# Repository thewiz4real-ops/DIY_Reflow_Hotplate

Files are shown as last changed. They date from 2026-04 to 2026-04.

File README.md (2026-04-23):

# DIY Reflow Hotplate

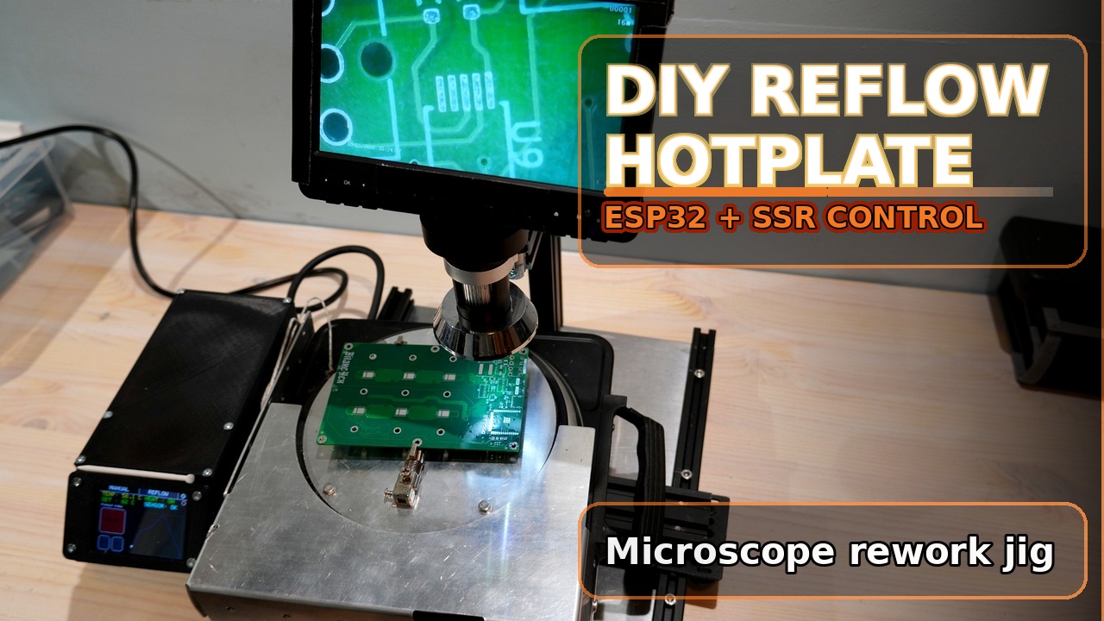
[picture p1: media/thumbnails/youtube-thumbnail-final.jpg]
DIY reflow hotplate thumbnail


DIY PCB reflow hotplate and microscope rework jig built around a 1500 W single-burner hotplate, a large aluminum work surface, and an ESP32 touchscreen controller.

The original goal was to make large-board repair and preheating easier under a microscope, then extend the same machine into a basic reflow station.

YouTube build video: [https://youtu.be/tEUVSpoKs-g](https://youtu.be/tEUVSpoKs-g)

> This is a hobby / experimental project, not a certified product. If you build, copy, modify, or use anything from this repo, you do so at your own risk and under your own responsibility.

## What is in this repo

- cleaned-up project documentation
- ESP-IDF 5.5 firmware in `firmware/esp-idf-5.5/`
- Arduino sketch version in `firmware/arduino/hotplate_controller/`
- BOM with part links and raw build notes in `bom/`
- CAD files for the main plate and the control box enclosure
- build photos and the final YouTube thumbnail

## Current status

This machine works as a PCB preheater and rework station, and it can also run a reflow profile. It is still an experimental build, and the main thing still left to tune is the final calibration between the displayed temperature and the real working surface.

If you want the full build sequence, the YouTube video is the best companion to this repo. The repo keeps the important design choices, troubleshooting notes, and source files, while the video shows the complete build process.

## Main features

- 1500 W hotplate base with aluminum top plate
- rotating work surface for microscope work
- hand rest / armature around the hot zone
- ESP32 touchscreen controller with graph UI
- SSR-controlled heater output
- 100k NTC temperature sensing
- manual mode, reflow mode, and saved settings
- controller mounted close to the moving work area

## Build summary

- The project started because the Betax Hex PCB had large copper planes that were difficult to reflow with hot air alone.
- The first version was a simple hotplate with a marked mechanical thermostat and a laser-thermometer-verified preheat point.
- The final direction became a safer microscope rework jig with a rotating plate, hand rest, motion system, and ESP32 touchscreen control.
- The most important fixes were the display driver setup, the wrong 3.3 V header-pin mistake, and removing the thermal gap between the hotplate and the work plate.

## Safety

This project uses mains voltage, high current, and hot metal surfaces.

It is shared as build documentation for a personal hobby project. I cannot take responsibility for injury, fire, property damage, or other loss caused by building or using this project.

- build it only if you understand the electrical and thermal risks
- bond all intended metal chassis parts to earth
- use proper insulation, strain relief, and enclosure design
- never leave the machine unattended while powered or hot
- if you replicate the controller power supply, use a properly enclosed certified 5 V PSU instead of modifying a loose phone charger

## Repo layout

- `bom/` parts list, purchase links, and raw source notes
- `docs/` overview, build notes, firmware notes, tuning notes, and safety notes
- `firmware/` Arduino and ESP-IDF firmware versions
- `hardware/` controller, enclosure, and wiring documentation
- `mechanical/` frame, armature, and CAD files
- `media/` build photos, thumbnail, and video link
- `notes/` GitHub publishing helpers

## Quick start

1. Read `docs/07_safety.md` first.
2. Start with `docs/01_project_overview.md` and `docs/02_mechanical_build.md`.
3. Use `bom/BOM.md` or `bom/BOM.csv` for parts.
4. Choose either the Arduino or ESP-IDF firmware path under `firmware/`.
5. Calibrate the machine before trusting the displayed temperature.

## Still to finish

- final calibration table that maps setpoint to real surface temperature

## Possible separate project

- A small controller PCB for the MOSFET and resistor section would be a natural spinoff from the current perfboard version.

## License

This repository is released under the MIT License. See `LICENSE`.

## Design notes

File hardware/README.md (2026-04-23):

# Hardware

This folder stores the controller hardware, enclosure files, and wiring notes.

## Main sections

- `controller-board/` for breadboard, perfboard, and controller-board notes
- `enclosure/` for the control box enclosure files
- `wiring/` for the pin map and wiring references

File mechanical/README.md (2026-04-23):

# Mechanical files

This folder stores the frame, armature, microscope mount, and CAD/CAM notes.

## Main sections

- `frame/` for the base structure and main plate CAD files
- `armature/` for the hand-rest / heat shield notes
- `microscope-mount/` for the microscope support

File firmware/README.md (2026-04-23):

# Firmware

Two firmware versions are included in this repo:

- `arduino/hotplate_controller/` for the Arduino IDE style sketch
- `esp-idf-5.5/` for the ESP-IDF 5.5 project using Arduino as a component

Both versions target the same ESP32 touchscreen controller and share the same basic feature set:

- Manual mode
- Reflow mode
- Settings page
- XPT2046 touch input
- NTC temperature reading
- SSR heater control
- settings saved in flash

## Shared pin summary

- NTC sensor: GPIO 35
- SSR output: GPIO 27
- touch IRQ: GPIO 36
- touch MOSI: GPIO 32
- touch MISO: GPIO 39
- touch CLK: GPIO 25
- touch CS: GPIO 33

## Important note

The display still depends on a correct `TFT_eSPI` configuration for the exact CYD board and panel driver.

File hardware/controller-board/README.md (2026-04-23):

# Controller board

The original build used:
1. a breadboard prototype
2. a perfboard implementation

This folder documents the controller-side hardware for the build.

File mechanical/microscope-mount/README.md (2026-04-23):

# Microscope mount

This folder covers the center-mounted microscope support used in the build.

The mount concept and layout are described in `docs/02_mechanical_build.md` and shown in the YouTube video.

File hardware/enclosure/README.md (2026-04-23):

# Electronics enclosure

3D printed enclosure for:
- SSR
- 5 V supply
- main power switch
- touchscreen window

Also note:
- zip-tie anchor holes
- cable routing channels
- relay bolt-through mount to aluminum chassis

## Files currently in the repo

The current source exports are under `cad/brain-box/`:

- `reflow-plate-brain-box.f3d`
- `reflow-plate-brain-box.3mf`
- `reflow-plate-brain-box.obj`
- `reflow-plate-brain-box.mtl`

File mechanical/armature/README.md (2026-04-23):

# Armature / hand-rest

Purpose:
- give a cooler place to rest the hand
- improve comfort during microscope work
- reduce accidental contact with the hot area

Build notes:
- made from 2 mm aluminum
- designed as a foldable sheet part
- grooves added to help controlled bending
- mounted with aluminum rivets
- spaced away from the hot zone with bolts / spacers

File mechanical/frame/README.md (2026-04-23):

# Frame

Main structure made from:
- 50 x 50 cm aluminum base plate
- T-slot profiles
- drilled and tapped mounting holes

Suggested things to document:
- exact profile lengths
- exact hole spacing
- wheel setup
- microscope mount dimensions
- control box bracket dimensions

## Files currently in the repo

The main plate CAD exports are in `cad/reflow-plate/`:

- `reflow-plate.f3d`
- `reflow-plate.3mf`
- `reflow-plate.obj`
- `reflow-plate.mtl`

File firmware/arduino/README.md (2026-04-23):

# Arduino Firmware

The Arduino version of the controller lives in `hotplate_controller/hotplate_controller.ino`.

## Expected libraries

- `TFT_eSPI`
- `XPT2046_Touchscreen`
- `Preferences`

## Notes

- this sketch targets the ESP32-2432S028 style CYD board
- touch and heater pins match the ESP-IDF version
- `TFT_eSPI` requires the correct board-specific `User_Setup.h`

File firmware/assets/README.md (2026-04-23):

# Firmware assets

The current interface is drawn directly in code.

This folder is available for any optional logos, icons, splash images, or calibration graphics associated with the firmware.

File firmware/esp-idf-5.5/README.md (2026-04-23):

# ESP-IDF 5.5 hotplate project

This project keeps the UI and control logic in Arduino-style C++, but runs inside an ESP-IDF project using Arduino as a component.

## What is included
- `main/main.cpp` contains the hotplate app
- raw XPT2046 touch handling is built into `main.cpp`
- `TEMP_OFFSET_C` is stored in Preferences / NVS
- settings selection uses one large `NEXT` button
- touch reading uses median filtering for better tap stability

## Dependency setup
Clone `TFT_eSPI` into `components/TFT_eSPI`.

Example:
```bash
cd components
git clone https://github.com/Bodmer/TFT_eSPI.git
```

Then copy the working `User_Setup.h` / `User_Setup_Select.h` into that library, because the display wiring and driver config live there.

## Build steps
```bash
idf.py set-target esp32
idf.py build
idf.py -p PORT flash monitor
```

## Notes
- Arduino is pulled in by `main/idf_component.yml`
- the `components/` folder is included so the `TFT_eSPI` checkout has a clear home
- touch uses these pins:
  - IRQ 36
  - MOSI 32
  - MISO 39
  - CLK 25
  - CS 33
- if touch still lands off near the edges, recalibrate:
  - `XMIN`
  - `XMAX`
  - `YMIN`
  - `YMAX`

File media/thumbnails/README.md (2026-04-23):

# Thumbnails

Current file:

- `youtube-thumbnail-final.jpg`

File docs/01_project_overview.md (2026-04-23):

# Project overview

## Why this was built

This project started after building the Betax Hex, a large PCB with heavy copper layers. Hot-air-only reflow was hard because the board absorbed heat too fast. Solder cooled quickly, alignment was poor, and rework was uncomfortable.

The target was a setup that is:
- stable
- safe to handle
- controllable
- repeatable
- usable under a microscope
- suitable for both repair work and reflow

## Final goal

One machine that can be used as:
- a heat plate for repair and preheating
- a reflow plate when needed
- a safer microscope work area with a hand-rest

## Build path

The project did not start as the final rail-based machine.

The first version was a 1500 W cooking hotplate with a 2 mm aluminum top plate and a PCB holder. Because the hotplate only had a mechanical thermostat, a laser thermometer was used to find and mark a repeatable preheat position around 100 C.

That first version proved the thermal idea, but it was awkward and unsafe to use under a microscope. Burned fingers and poor ergonomics pushed the project toward a full mechanical redesign with a hand rest, motion system, rotating work area, and ESP32 control box.

## Full build log

The repo keeps the key files and lessons learned. For the full sequence of fabrication and assembly steps, use the YouTube video linked from the main `README.md`.

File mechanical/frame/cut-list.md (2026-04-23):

# Frame cut list

This cut list includes the dimensions that were clearly recorded during the build.

| Part | Material | Qty | Length / Size | Notes |
|---|---|---:|---|---|
| Base plate | Aluminum | 1 | 500 x 500 x 10 mm | Main base |
| Top working plate | Aluminum | 1 | 8 mm or 10 mm | Builder used 10 mm plate |
| Secondary plate | Aluminum | 1 | Match top plate footprint | Final no-gap thermal fix |
| 2040 profile | T-slot | 1 | 500 mm | Explicitly mentioned in raw notes |
| Additional frame profiles | T-slot | Varies | Varies by build | Depends on the final rail and microscope layout |
| Gantry plate | Off-the-shelf wheel carriage | Varies | 80 mm format | Motion assembly part |
| Control box bracket | Aluminum | 1 | Custom fit | Dimensions follow the finished control-box position |

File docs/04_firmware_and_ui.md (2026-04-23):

# Firmware and UI

## Repo layout
- Arduino sketch: `firmware/arduino/hotplate_controller/hotplate_controller.ino`
- ESP-IDF project: `firmware/esp-idf-5.5/`

## Hardware stack
- ESP32 touchscreen board
- TFT_eSPI for display
- XPT2046 for touch
- Preferences / NVS for saved settings

## Why not LVGL
LVGL caused configuration and version mismatch problems during development, so the firmware moved to a simpler TFT_eSPI + XPT2046 setup.

The main problems were missing `lv_conf.h` setup and LVGL v8/v9 mismatch issues during compile-time testing.

## Display bring-up problems

Early display tests had split-screen output, noise, and black-screen behavior.

The working fix was:
- use the `ILI9341_2` driver configuration
- enable `TFT_INVERSION_ON`

That combination gave a stable display on the CYD hardware used in this build.

## UI structure
- Manual tab
- Reflow tab
- Settings tab

## Manual mode
- user selects temperature
- ramped setpoint behavior helps reduce overshoot
- can be used like a repair / preheat mode

## Reflow mode
- full profile
- stage display
- graph / progress indicator
- pause behavior if the plate falls behind the profile

## Settings
- approach band
- burst window
- max power limit
- values saved in flash

## Shared control I/O
- NTC ADC input on GPIO 35
- heater output on GPIO 27
- XPT2046 touch on GPIO 36, 32, 39, 25, and 33

## UI optimization
- small-region redraw instead of full-screen redraw
- touch debouncing / better click handling
- improved touch stability from debounce and target locking behavior
- improved stability and reduced flicker

## Important setup note
`TFT_eSPI` relies on a working `User_Setup.h` / `User_Setup_Select.h` for the specific CYD display wiring and driver configuration.

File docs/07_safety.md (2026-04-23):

# Safety

This repo documents a hobby / experimental project. It is not a certified appliance, a commercial product, or a guarantee that the design is safe for replication.

If you build, copy, modify, or use anything from this project, you do so at your own risk and under your own responsibility. The builder of this repo cannot take responsibility for injury, fire, property damage, or other loss.

This project uses:
- mains voltage
- high current
- hot surfaces
- exposed metal structure near electrical parts

## Minimum safety expectations
- earth / ground all intended metal chassis parts
- check continuity from mains earth to grounded metal parts
- secure cables so they cannot move
- keep mains and low-voltage wiring organized
- use proper strain relief
- insulate exposed joints
- mount the SSR correctly
- verify the enclosure is safe before power-on
- do not leave the machine unattended

## Public repo recommendation
Treat the repo as documentation of an experimental build, not a certification claim.

Suggested wording:
> Build and use at your own risk. This is a hobby project, not a certified commercial appliance.

## Safer design ideas
If you ever make a more replication-focused version, add:
- proper cable gland
- independent thermal cutoff / fuse
- dedicated earth lug to chassis
- safer low-voltage PSU choice
- standard sensor mounting method

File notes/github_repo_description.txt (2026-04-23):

DIY PCB reflow hotplate and microscope rework jig with ESP32 touchscreen control, SSR heater switching, custom aluminum mechanics, and Arduino + ESP-IDF firmware.

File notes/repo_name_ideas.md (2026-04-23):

# Repo name ideas

- diy-reflow-hotplate
- esp32-reflow-hotplate
- microscope-rework-hotplate
- pcb-preheater-rework-jig
- diy-hotplate-rework-station

Simple recommendation:
`diy-reflow-hotplate`

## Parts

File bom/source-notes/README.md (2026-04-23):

# Source Notes

`mybom_raw_links.txt` is the original rough purchase list from the build. It is kept here as a raw reference so the cleaned BOM files can stay readable without losing the original notes.

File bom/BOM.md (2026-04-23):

# Bill of Materials

This is the main human-readable BOM for the project. It merges the cleaned part list with the original rough purchase links so the important URLs, part numbers, and notes are all in one place.

Use `BOM.csv` if you want to sort or filter the same list in a spreadsheet.

## Main BOM

| Category | Item | Qty | Link / Source | Part number | Notes |
|---|---|---:|---|---|---|
| Hotplate | Day single burner hotplate, 18 cm, 1500 W | 1 | https://www.megaflis.no/kjokken/kjokkenapparater/diverse-kjokkenapparater/day-kokeplate-o18cm-1500w? |  | Main heater base |
| Mechanical | Aluminum top plate | 1 | https://www.aliexpress.com/item/1005009533760651.html |  | Builder note says 8 mm or 10 mm works; this build used 10 mm |
| Mechanical | Aluminum base plate | 1 | Local / custom stock |  | 500 x 500 x 10 mm main base plate |
| Mechanical | Secondary aluminum plate | 1 | Reused part |  | Added during the final no-gap thermal fix |
| Mechanical | Armature sheet | 1 | Local / custom stock |  | 2 mm aluminum sheet for the hand rest / armature |
| Motion | 80 mm gantry plate | 1 | https://www.temu.com/goods.html?_bg_fs=1&goods_id=601099519049945 |  | V-slot gantry plate used in the motion assembly |
| Motion | V-slot wheel kit | 2 | https://www.temu.com/no-en/3d-printer-additions-for--v-shaped--plate-set-special-skate-wheels-compatible-with-2020-2040-v-slot-profiles-g-606143246110085.html |  | Openbuild-style wheel set for 2020 / 2040 profiles |
| Motion | T-slot extrusion | Varies | https://www.temu.com/no-en/t-slot-2020-extrusion-european-standard-anodized-linear-rail-for-3d-printer-parts-and-cnc-diy-black-g-606341536023071.html |  | Black anodized extrusion for frame and microscope support; lengths depend on the final cut list |
| Motion | 2040 extrusion, 500 mm | 1 | https://www.aliexpress.com/item/1005004784760394.htm |  | Explicitly mentioned in the raw notes |
| Motion | Extrusion bracket set | 1 kit | https://www.temu.com/goods.html?_bg_fs=1&goods_id=601099554813640 |  | Joint plates, T-nuts, and M5 x 8 mm screws for the frame |
| Electronics | ESP32-2432S028 CYD display board | 1 | https://www.aliexpress.com/item/1005008314695130.html |  | Main controller |
| Electronics | Crydom D2425 SSR | 1 | Digikey | D2425 / CC1006-ND | SSR relay, SPST-NO, 25 A, 24-280 V |
| Electronics | NTC thermistor | 1 | Digikey | NRBG105F3950B1F / 283-NRBG105F3950B1F-ND | 100k NTC, beta 3950, 1 percent |
| Electronics | IRLZ44NPBF MOSFET | 1 | Generic supplier / existing stock | IRLZ44NPBF | Used in the driver section |
| Electronics | Perfboard | 1 | Generic supplier / existing stock |  | Used for the final controller wiring |
| Electronics | JST-style connectors | 2 | Generic supplier / existing stock |  | JST-style plug connectors were used on the perfboard build; quantity is a builder estimate |
| Electronics | Resistor assortment | 1 pack | Generic supplier / AliExpress |  | Raw note says generic resistor package from AliExpress |
| Power | 5 V phone charger | 1 | Reused part |  | Original build reused this for ESP32 power; safer enclosed PSU is recommended for copies |
| Power | Power switch from extension strip | 1 | https://www.biltema.no/bygg/elektro/grenkontakter/grenkontakt-jordet/grenuttak-med-bryter-5-veis-hvitt-15-m-2000048332 |  | Original build reused only the switch |
| Optics | Digital microscope | 1 | https://www.temu.com/goods.html?_bg_fs=1&goods_id=601099593977408 |  | DM9-style microscope with LED lighting |
| Fasteners | M4 hex-head screws | Varies | Local hardware store / existing stock |  | Used throughout the tapped aluminum parts; length depends on mounting location |
| Fasteners | Wood screws, 3 x 15 mm | 1 pack | https://www.biltema.no/bygg/festeelementer/treskruer/treskrue-3-x-15-200-stk-2000058078 |  | Utility screw pack used during the build |
| Wiring | Hookup wire | As needed | Generic supplier / existing stock |  | Thin stranded wire used like manual traces on perfboard |
| Wiring | Mains cable | 1 | Generic supplier / existing stock |  | Use proper strain relief and enclosure routing |
| Consumables | UV resin | 1 | Generic supplier / existing stock |  | Used to secure and insulate some mains-side joints |
| Consumables | Ceramic cement | 1 | Generic supplier / existing stock |  | Used during one thermistor mounting experiment |
| Consumables | Fiberglass gasket | 1 | Generic supplier / existing stock |  | 6 mm; used in one thermal gap experiment |
| Tools | M4 tap | 1 | Local hardware store / existing stock |  | Used for tapping threaded holes in the aluminum parts |
| Tools | Profile drilling guide | 1 | https://www.temu.com/no-en/drilling-guide-for-vertical--designed-for-20-30-and-40-aluminum-profiles-featuring-sliders-and-an-m6-countersunk-step-drill-g-601103103107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 |  | Optional helper for aluminum profiles |
| Tools | Laser thermometer | 1 | Existing tool |  | Used to find a repeatable early preheat point |
| Tools | Hot air gun | 1 | Existing tool |  | Used during rework and bench testing |

## Notes

- Quantities marked `Varies` or `As needed` depend on the exact build layout rather than a single fixed number.
- The original rough purchase note file is still kept in `source-notes/mybom_raw_links.txt` as an archive, but the important link data is merged into this file.
- For public safety, it is better to recommend a properly enclosed certified 5 V PSU instead of copying the reused phone-charger approach from the original build.

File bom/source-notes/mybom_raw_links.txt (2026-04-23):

https://www.aliexpress.com/item/1005009533760651.html Aluminum Metal Shee 8mm or 10mm wil work, mine was 10mm

https://www.aliexpress.com/item/1005008314695130.html ESP32 MCU 2.8 Inch Smart Display for Arduino

https://www.temu.com/goods.html?_bg_fs=1&goods_id=601099593977408 Microscope with Leds 1200X Magnification DM9 1080P HD Soldring Microscope for Electronics Repair

https://www.temu.com/goods.html?_bg_fs=1&goods_id=601099519049945 80Mm Gantry Plate with Wheels for Profiles V-Slot Plate Kits Plat V-Openbuildd

https://www.temu.com/no-en/3d-printer-additions-for--v-shaped--plate-set-special-skate-wheels-compatible-with-2020-2040-v-slot-profiles-g-606143246110085.html 
Openbuild, V-Shaped Gantry Plate Set, Special Skate Wheels, Compatible with 2020/2040 V-Slot Profiles

https://www.temu.com/no-en/t-slot-2020-extrusion-european-standard-anodized-linear-rail-for-3d-printer-parts-and-cnc-diy-black-g-606341536023071.html
Standard Anodized Linear Rail for 3D Printer Parts and CNC DIY Black

https://www.temu.com/no-en/drilling-guide-for-vertical--designed-for-20-30-and-40-aluminum-profiles-featuring-sliders-and-an-m6-countersunk-step-drill-g-601103103107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
Punchers Designed for 20#, 30#, And 40# Aluminum Profiles, Featuring Sliders And an M6 Countersunk Step Drill

https://www.aliexpress.com/item/1005004784760394.htm
1PCS 2040 500mm

https://www.biltema.no/bygg/festeelementer/treskruer/treskrue-3-x-15-200-stk-2000058078
Treskrue 3 x 15, 200 stk.

https://www.temu.com/goods.html?_bg_fs=1&goods_id=601099554813640
Extrusion Bracket Set - Including 8pcs Joint Plates, 1pc M3 Wrench, 40pcs M5 T-Slot Nuts, 40pcs M5x8mm Screws, For 3D Printer Frame

digikey

283-NRBG105F3950B1F-ND
NRBG105F3950B1F
NTC 100K 3950K BETA 25/50 1%

CC1006-ND
D2425
SSR RELAY SPST-NO 25A 24-280V

mosfet
IRLZ44NPBF

generic resistor package from AliExpress

power buton from this removit from this extenstion cable
https://www.biltema.no/bygg/elektro/grenkontakter/grenkontakt-jordet/grenuttak-med-bryter-5-veis-hvitt-15-m-2000048332

Day kokeplate ø18cm 1500w
https://www.megaflis.no/kjokken/kjokkenapparater/diverse-kjokkenapparater/day-kokeplate-o18cm-1500w?

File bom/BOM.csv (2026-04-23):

Category | Item | Description | Qty | Status | Link | Notes
Hotplate | Day single burner hotplate | 18 cm, 1500 W hotplate used as the heater base | 1 | Used in build | https://www.megaflis.no/kjokken/kjokkenapparater/diverse-kjokkenapparater/day-kokeplate-o18cm-1500w? | Main heater base
Mechanical | Top aluminum plate | Aluminum sheet for the heated work surface | 1 | Used in build | https://www.aliexpress.com/item/1005009533760651.html | Builder note says 8 mm or 10 mm works and this build used 10 mm
Mechanical | Base plate | Main aluminum base plate | 1 | Used in build |  | 500 x 500 x 10 mm
Mechanical | Secondary aluminum plate | Second plate used during the final no-gap thermal fix | 1 | Used in build |  | Stacked directly with the top plate
Mechanical | Armature sheet | 2 mm aluminum sheet for the hand rest / armature | 1 | Used in build |  | Folded sheet-metal style part
Motion | 80 mm gantry plate | V-slot gantry plate used in the motion assembly | 1 | Used in build | https://www.temu.com/goods.html?_bg_fs=1&goods_id=601099519049945 | Single gantry plate used in the motion assembly
Motion | V-slot wheel kit | Wheel set for 2020 / 2040 profiles | 2 | Used in build | https://www.temu.com/no-en/3d-printer-additions-for--v-shaped--plate-set-special-skate-wheels-compatible-with-2020-2040-v-slot-profiles-g-606143246110085.html | Two kits used in the build
Motion | T-slot extrusion | Black anodized extrusion for frame and microscope support | Varies | Used in build | https://www.temu.com/no-en/t-slot-2020-extrusion-european-standard-anodized-linear-rail-for-3d-printer-parts-and-cnc-diy-black-g-606341536023071.html | Lengths depend on the final cut list
Motion | 2040 extrusion 500 mm | One explicitly noted 2040 profile length from the build notes | 1 | Used in build | https://www.aliexpress.com/item/1005004784760394.htm | Raw note says 1 pcs 2040 500 mm
Motion | Extrusion bracket set | Joint plates, T-nuts, and M5 screws for the frame | 1 kit | Used in build | https://www.temu.com/goods.html?_bg_fs=1&goods_id=601099554813640 | Frame hardware kit
Tools | Profile drilling guide | Drilling guide for aluminum profiles | 1 | Tool | https://www.temu.com/no-en/drilling-guide-for-vertical--designed-for-20-30-and-40-aluminum-profiles-featuring-sliders-and-an-m6-countersunk-step-drill-g-60110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 | Optional build helper
Electronics | ESP32-2432S028 | 2.8 in CYD touchscreen board | 1 | Used in build | https://www.aliexpress.com/item/1005008314695130.html | Main controller
Electronics | Crydom D2425 SSR | 25 A solid-state relay | 1 | Used in build |  | Digikey part CC1006-ND
Electronics | NTC thermistor | 100k NTC, beta 3950, 1 percent | 1 | Used in build |  | Digikey part 283-NRBG105F3950B1F-ND
Electronics | IRLZ44NPBF MOSFET | MOSFET used in the driver section | 1 | Used in build |  | Part number from raw notes
Electronics | Perfboard | Perfboard used for the final controller wiring | 1 | Used in build |  | Controller board
Electronics | JST-style connectors | Plug connectors used on the perfboard build | 2 | Used in build |  | JST-style connectors were used on the perfboard build; quantity is a builder estimate
Electronics | Resistor assortment | Generic resistor pack used during the build | 1 pack | Used in build |  | Raw note says generic resistor package from AliExpress
Power | 5 V phone charger | Repurposed as the ESP32 power supply in the original build | 1 | Used in build |  | Public recommendation is to replace this with an enclosed certified PSU
Power | Power switch | Switch salvaged from a grounded power strip | 1 | Used in build | https://www.biltema.no/bygg/elektro/grenkontakter/grenkontakt-jordet/grenuttak-med-bryter-5-veis-hvitt-15-m-2000048332 | Original build reused the switch only
Optics | Digital microscope | DM9-style microscope with LED lighting | 1 | Used in build | https://www.temu.com/goods.html?_bg_fs=1&goods_id=601099593977408 | Used over the work surface
Fasteners | Wood screws | 3 x 15 mm screw pack | 1 pack | Used in build | https://www.biltema.no/bygg/festeelementer/treskruer/treskrue-3-x-15-200-stk-2000058078 | Utility screw pack used during the build
Fasteners | M4 hex-head screws | Hex-head machine screws used with tapped aluminum parts | Varies | Used in build |  | Length depends on mounting location
Wiring | Hookup wire | Thin stranded wire used like manual traces on perfboard | As needed | Used in build |  | Thin stranded wire used like manual traces on perfboard
Wiring | Mains cable | Input power cable | 1 | Used in build |  | Use proper strain relief and enclosure routing
Consumables | UV resin | Used to secure and insulate some mains-side joints | 1 | Used in build |  | Treat this as experimental build documentation only
Consumables | Ceramic cement | Used during one thermistor mounting experiment | 1 | Experiment |  | Not part of the final preferred setup
Consumables | Fiberglass gasket | Used in one thermal gap experiment | 1 | Experiment |  | 6 mm
Tools | M4 tap | Used for tapping threaded holes in the aluminum parts | 1 | Used in build |  | For threading aluminum holes
Tools | Laser thermometer | Used to find a repeatable early preheat point | 1 | Tool |  | Early calibration method
Tools | Hot air gun | Used during rework and testing | 1 | Tool |  | Not part of the machine itself

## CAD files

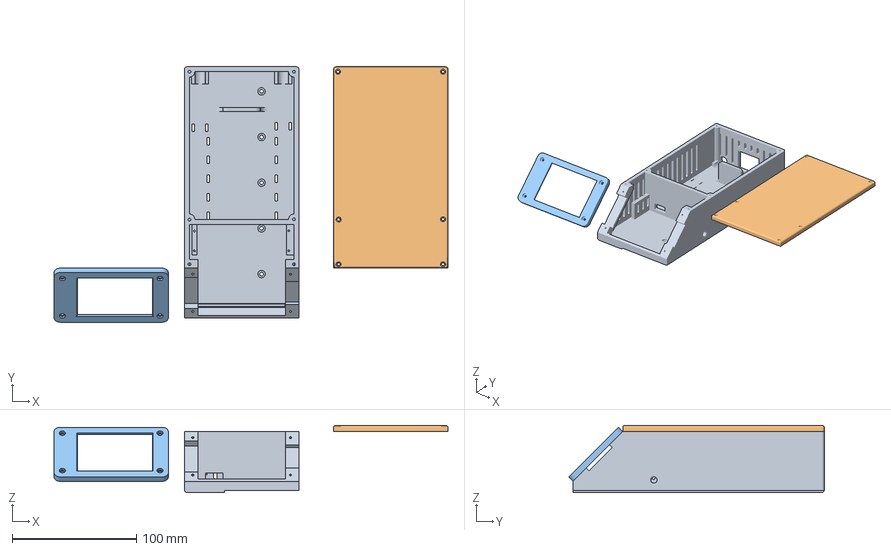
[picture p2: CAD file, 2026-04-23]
hardware/enclosure/cad/brain-box/reflow-plate-brain-box.3mf
317.0 x 205.6 x 54.0 mm

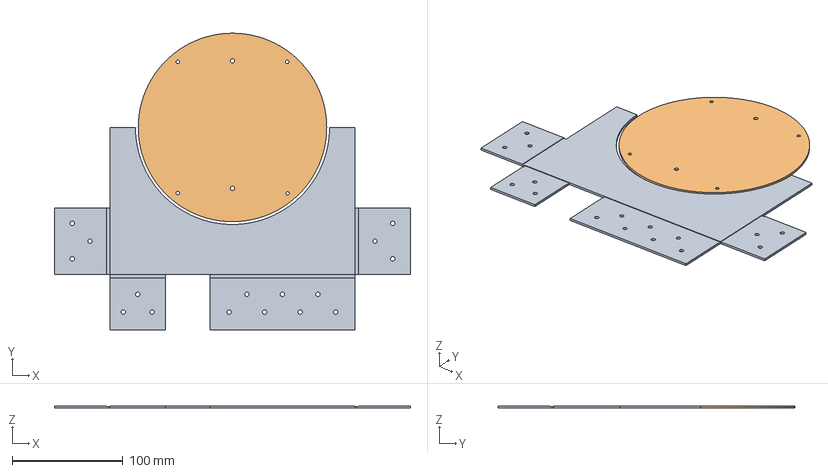
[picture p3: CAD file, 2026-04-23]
mechanical/frame/cad/reflow-plate/reflow-plate.3mf
321.0 x 267.5 x 2.00 mm

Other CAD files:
hardware/enclosure/cad/brain-box/reflow-plate-brain-box.f3d
hardware/enclosure/cad/brain-box/reflow-plate-brain-box.obj
mechanical/frame/cad/reflow-plate/reflow-plate.f3d
mechanical/frame/cad/reflow-plate/reflow-plate.obj

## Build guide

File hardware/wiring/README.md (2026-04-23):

# Wiring

This folder contains the wiring-side reference material included in the repo.

The current public wiring reference is:
- `connector_map.md` for the firmware-side pin map
- the YouTube build video for the physical routing and assembly details

## Recommended public note
If you share wiring publicly, clearly mark:
- mains section
- low-voltage section
- grounded chassis points
- sensor wiring
- SSR wiring
- switch wiring

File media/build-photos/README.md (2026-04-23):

# Build Photos

Current photos in this folder:

- `assembled-hotplate-under-microscope.jpg`
- `parts-layout.jpg`

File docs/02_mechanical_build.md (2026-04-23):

# Mechanical build

## Early hotplate version
- 1500 W cooking hotplate used as the starting point
- 2 mm aluminum top plate added above it
- PCB holder mounted on top
- laser thermometer used to find a repeatable preheat position on the mechanical knob

## Base
- 50 x 50 cm aluminum base plate
- 10 mm thick
- drilled and tapped for the frame and rails

## Frame and motion
- T-slot profiles cut to length with a miter saw
- holes measured, drilled, and tapped
- 20 x 40 profiles used for the main motion structure
- Y-axis initially too tight
- inner wheels were removed so the motion became smoother
- final system supports movement and plate rotation

## Microscope support
- center-mounted support built from T-slot extrusion
- designed to keep the microscope aligned over the work area

## Armature / hand rest
- designed as a foldable part in CAD from 2 mm aluminum sheet
- bend grooves were added to make forming easier
- toolpaths and G-code were generated in Kiri:Moto
- cut on a DIY CNC with plywood sacrificial board, double-sided tape, and clamps
- bent with a simple wood jig
- mounted with aluminum rivets and spacers to keep a cooler air gap from the hot zone

## Control box mount
- custom aluminum bracket connects the control box to the moving plate assembly
- screen and controls stay near the work area
- cable pull is reduced during movement

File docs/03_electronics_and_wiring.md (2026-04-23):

# Electronics and wiring

## Main controller
- ESP32-2432S028 (CYD touchscreen board)

## Heater power switching
- Crydom D2425 solid-state relay (SSR)
- bolted to the aluminum chassis for heat transfer and grounding

## Temperature sensing
- 100k NTC sensor
- beta 3950
- original part note from the build: NRBG105F3950B1F

## Pin map

The current firmware-side I/O map is documented in `hardware/wiring/connector_map.md`.

## Prototyping path
1. Breadboard proof-of-concept
2. Bench testing with a desk lamp and hot air to validate the sensor, relay, and UI
3. Perfboard implementation
4. JST-style plug connections for cleaner wiring
5. Final enclosure assembly

## Perfboard wiring method
Instead of making long solder blobs between holes, thin stranded wire was used like a manual trace. The wire was soldered down along the full path to make the connection clean and solid.

## Main debugging issue
A signal/header pin was accidentally used where the board should have been powered from the correct 3.3 V rail. That caused the sensor supply to sag whenever the MOSFET / relay load switched, which showed up as false temperature spikes.

Moving the supply to the correct 3.3 V pin on the board fixed that instability.

## Power and enclosure
- the original build reused an old 5 V phone charger for ESP32 power
- mains wiring for the charger input and power switch was soldered and reinforced with UV resin
- the enclosure was 3D printed for the SSR, charger, main switch, and touchscreen opening
- hotplate body and aluminum chassis were grounded
- cable routing channels and zip ties were used to keep the mains wiring under control

## Mains wiring note
The original build reused a phone charger for 5 V and used mains wiring inside the box. Keep this part clearly marked as hazardous in the public repo.

Recommended public-facing note:
> If you want to replicate this build, use a properly enclosed certified 5 V PSU unless you are qualified to modify mains-powered supplies.

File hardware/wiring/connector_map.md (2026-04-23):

# Connector map

This is the current firmware-side I/O map gathered from the checked-in code.

## ESP32 controller pins

| Function | Pin / Part | Notes |
|---|---|---|
| NTC sensor ADC input | GPIO 35 | Input-only ADC pin |
| Heater output | GPIO 27 | Drives SSR or MOSFET stage, active high in current code |
| Touch IRQ | GPIO 36 | XPT2046 touch controller |
| Touch MOSI | GPIO 32 | XPT2046 touch controller |
| Touch MISO | GPIO 39 | XPT2046 touch controller |
| Touch CLK | GPIO 25 | XPT2046 touch controller |
| Touch CS | GPIO 33 | XPT2046 touch controller |

## Sensor network

| Item | Value | Notes |
|---|---|---|
| Thermistor | 100k NTC | Beta 3950 |
| Fixed resistor | 10k | Used in the divider math in firmware |

## Build notes

This file focuses on the firmware-side pin map.

The physical wire routing, connector placement, and mains layout are shown more clearly in the project video and the broader build notes than in a single fixed table.

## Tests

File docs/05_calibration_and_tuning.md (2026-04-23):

# Calibration and tuning

## Early method
The first version used a mechanical hotplate knob and a laser thermometer to find a repeatable 100 C preheat setting.

## Sensor problems found during the build
- a 6 mm gap between the hotplate and the aluminum plate created a large mismatch between sensed temperature and actual top surface temperature
- sensor placement inside the gap did not reflect the real working surface
- the sensor wire itself transferred heat and distorted readings

## Experiments
1. fiberglass gasket at the edge of the gap
2. moving the sensor toward the center
3. drilling a hole and fixing the sensor with ceramic cement
4. moving the sensor to the top surface
5. removing the gap entirely

The fiberglass gasket helped slightly, but not enough. The center-mounted ceramic-cement attempt also failed to solve the problem because the sensor wiring still had to pass through the gap.

The biggest clue was realizing that the sensor wire trapped between the plates was conducting heat into the sensor and creating a large reading error.

## Current result
The final fix was removing the gap completely, stacking the old aluminum plate with the newer one, screwing both directly to the hotplate, and placing the sensor on top. That made the reflow behavior much more believable and left final calibration as the main remaining tuning task.

## Calibration focus
- real calibration table between setpoint and surface temperature

## Recommended next calibration step
- measure with a surface thermocouple placed directly on the work area
- compare real plate temperature against the displayed temperature
- record offset and overshoot at several setpoints before attempting unattended profiles

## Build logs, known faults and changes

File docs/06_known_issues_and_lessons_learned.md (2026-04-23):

# Known issues and lessons learned

## Mechanical
- Y-axis was too tight until the wheel setup was changed
- the control box was first mounted too low and hit the X-axis, so it had to be moved higher

## Electrical
- wrong 3.3 V source caused long debugging sessions
- breadboard success did not guarantee perfboard success
- clear connector labeling matters
- simple power mistakes can look like sensor or firmware bugs

## Thermal
- air gap idea looked good in theory but acted more like an insulator
- sensor wire placement mattered more than expected
- sensor temperature and working surface temperature can differ a lot

## Firmware / display
- LVGL was more trouble than it was worth for this build
- the CYD display needed the right driver and inversion settings to stop split-screen / black-screen problems
- small partial redraws were much better than redrawing the full screen

## Build philosophy lesson
Many of the best decisions in this project came from actually using the machine:
- burned fingers
- awkward PCB handling
- cable drag
- wheel friction
- unstable temperature readings

That is also the strongest story in the repo: the build evolved because of real use.

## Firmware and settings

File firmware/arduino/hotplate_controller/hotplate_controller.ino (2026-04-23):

#include <Arduino.h>
#include <SPI.h>
#include <math.h>
#include <TFT_eSPI.h>
#include <XPT2046_Touchscreen.h>
#include <Preferences.h>   // save settings in flash (ESP32 NVS)

// ========= SCREEN =========
static constexpr int W = 320;
static constexpr int H = 240;
static constexpr uint8_t TFT_ROT = 3; // your working rotation
TFT_eSPI tft;

// ========= PINS =========
static constexpr int PIN_NTC = 35; // ADC input-only
static constexpr int PIN_SSR = 27; // SSR/MOSFET output (relay drive)

// Touch pins (common CYD)
#define XPT2046_IRQ 36
#define XPT2046_MOSI 32
#define XPT2046_MISO 39
#define XPT2046_CLK 25
#define XPT2046_CS 33

SPIClass touchSPI(VSPI);
XPT2046_Touchscreen touchscreen(XPT2046_CS, XPT2046_IRQ);

// If SSR polarity is backwards, flip this:
static constexpr bool SSR_ACTIVE_HIGH = true;

// ========= NTC =========
static constexpr float NTC_R0   = 100000.0f;
static constexpr float NTC_BETA = 3950.0f;
static constexpr float NTC_T0K  = 273.15f + 25.0f;
static constexpr float R_FIXED  = 10000.0f;
static constexpr float VREF     = 3.3f;

// ========= TOUCH CAL =========
// If edge taps are still off, these 4 values are the next thing to recalibrate.
static constexpr int XMIN = 200, XMAX = 3700;
static constexpr int YMIN = 240, YMAX = 3800;

// ========= CONTROL =========
static float setC = 100.0f;
static bool heatOn = false;         // USER "enabled" in Manual mode
static float tempC = 0.0f;          // display/control temp (offset applied)
static float tempSensorC = 0.0f;    // filtered sensor temp (raw, no offset)
static bool sensorOK = false;
static constexpr float MIN_SET = 0.0f;
static constexpr float MAX_SET = 450.0f;
static constexpr float HYST = 2.0f; // kept (not used by burst logic)

// Display SET number (manual set or reflow set/peak)
static float activeSetForDisplay = 100.0f;

// ========= MODE =========
enum Mode { MODE_MANUAL, MODE_REFLOW, MODE_SETTINGS };
static Mode mode = MODE_MANUAL;

// ========= REFLOW =========
static bool reflowRunning = false;  // USER "enabled" in Reflow mode
static uint32_t reflowStartMs = 0;
static float peakC = 240.0f; // default peak
static constexpr float REFLOW_TOTAL_S = 420.0f;
static constexpr float PLOT_STEP_S = 5.0f;

// program time that can PAUSE (this is what we use instead of wall-clock time)
static float    reflowProgS = 0.0f;
static uint32_t reflowLastTickMs = 0;

// allowed lag before pausing (degC)
static constexpr float REFLOW_SYNC_BAND_C = 3.0f;

// ========= UI LAYOUT =========
static constexpr int TAB_H  = 28;     // tab bar height
static constexpr int INFO_Y = 72;     // info line below values
static constexpr int PLOT_Y = 86;     // plot starts below info line

// LEFT column width for buttons
static constexpr int SIDE_W = 110;

// Plot moved right (left column for buttons)
static constexpr int PLOT_X = SIDE_W + 10;
static constexpr int PLOT_W = W - PLOT_X - 10;
static constexpr int PLOT_H = H - PLOT_Y - 6;

struct Rect { int x,y,w,h; };

// Tabs: Manual & Reflow wide, Settings tiny (gear icon)
static constexpr int SET_TAB_W   = 36;
static constexpr int MAIN_TABS_W = W - SET_TAB_W;
static constexpr int MAN_W       = MAIN_TABS_W / 2;
static constexpr int REF_W       = MAIN_TABS_W - MAN_W;

static Rect tabManualR = {0,              0, MAN_W,     TAB_H};
static Rect tabReflowR = {MAN_W,          0, REF_W,     TAB_H};
static Rect tabSetR    = {MAN_W + REF_W,  0, SET_TAB_W, TAB_H};

static Rect btnMinusR, btnHeatR, btnPlusR;

// ========= OUTPUT (SSR/MOSFET) STATE =========
static bool relayOn = false;                // actual GPIO27 drive state
static bool lastRelayOnDrawn = false;

// Small dot indicator for GPIO27 output state (green=ON, red=OFF)
static constexpr int RELAY_DOT_X = W - 14;
static constexpr int RELAY_DOT_Y = 38;
static constexpr int RELAY_DOT_R = 7;

// ========= SENSOR DEBOUNCE =========
static constexpr uint8_t SENSOR_BAD_TRIP     = 4;
static constexpr uint8_t SENSOR_GOOD_RECOVER = 2;
static uint8_t sensorBadCnt  = 0;
static uint8_t sensorGoodCnt = 0;

// ========= STATE FOR NO-FLICKER REDRAW =========
static Mode  lastModeDrawn      = MODE_MANUAL;
static bool  lastHeatOnDrawn    = false;
static bool  lastReflowRunDrawn = false;
static bool  lastSensorDrawn    = true;
static float lastSetDrawn       = -999.0f;
static float lastTempDrawn      = -999.0f;

// ========= PLOT STATE =========
static int lastProgIdx = -1;
static int lastDotX = -1, lastDotY = -1;
static int lastDotIdx = -1;

// ========= MANUAL HISTORY PLOT =========
static float manualHist[PLOT_W];
static bool manualHistInit = false;

// ========= Manual ramp + hold =========
static float    manualRampSetC   = 25.0f;   // internal ramped setpoint
static uint32_t manualRampLastMs = 0;

static constexpr float MANUAL_RAMP_CPS    = 0.6f; // degC per second ramp rate
static constexpr float MANUAL_SYNC_BAND_C = 3.0f; // pause ramp if behind more than this band

// ========= Burst PWM settings (saved) =========
static float    APPROACH_BAND_C = 25.0f;   // start pulsing within this many °C of target
static uint32_t WINDOW_MS       = 2000;    // burst window (ms), good for zero-cross SSR

// Max power limit to prevent runaway with thermal lag (saved)
static float MAX_DUTY = 0.40f;             // 0.10..1.00 (40% default)

// ========= Temp offset (saved) =========
static float TEMP_OFFSET_C = 0.0f;         // board temp correction
static constexpr float OFS_MIN  = -50.0f;
static constexpr float OFS_MAX  =  50.0f;
static constexpr float OFS_STEP =  1.0f;

static Preferences prefs;

static constexpr float    BAND_MIN  = 5.0f;
static constexpr float    BAND_MAX  = 80.0f;
static constexpr float    BAND_STEP = 5.0f;

static constexpr uint32_t WIN_MIN  = 500;
static constexpr uint32_t WIN_MAX  = 5000;
static constexpr uint32_t WIN_STEP = 250;

static constexpr float PWR_MIN  = 0.10f;
static constexpr float PWR_MAX  = 1.00f;
static constexpr float PWR_STEP = 0.05f;   // 5%

static constexpr int SETTINGS_COUNT = 4;

// settings selection (0=Approach, 1=Window, 2=Max power, 3=Temp offset)
static int settingsSel = 0;
static Rect settingsNextR;

// ========= UTIL =========
static float clampf(float v, float lo, float hi){
  if(v < lo) return lo;
  if(v > hi) return hi;
  return v;
}

static bool inRect(const Rect& r, int x, int y){
  return (x >= r.x && x < r.x + r.w && y >= r.y && y < r.y + r.h);
}

static int median3(int a, int b, int c){
  if(a > b){ int t = a; a = b; b = t; }
  if(b > c){ int t = b; b = c; c = t; }
  if(a > b){ int t = a; a = b; b = t; }
  return b;
}

static void ssrWrite(bool on){
  if(SSR_ACTIVE_HIGH) digitalWrite(PIN_SSR, on ? HIGH : LOW);
  else                digitalWrite(PIN_SSR, on ? LOW : HIGH);
}

// load/save settings (ESP32 NVS)
static void loadSettings(){
  prefs.begin("hotplate", true);
  APPROACH_BAND_C = prefs.getFloat("band", APPROACH_BAND_C);
  WINDOW_MS       = prefs.getUInt("win",  WINDOW_MS);
  MAX_DUTY        = prefs.getFloat("pwr", MAX_DUTY);
  TEMP_OFFSET_C   = prefs.getFloat("ofs", TEMP_OFFSET_C);
  prefs.end();

  APPROACH_BAND_C = clampf(APPROACH_BAND_C, BAND_MIN, BAND_MAX);
  if(WINDOW_MS < WIN_MIN) WINDOW_MS = WIN_MIN;
  if(WINDOW_MS > WIN_MAX) WINDOW_MS = WIN_MAX;
  MAX_DUTY = clampf(MAX_DUTY, PWR_MIN, PWR_MAX);
  TEMP_OFFSET_C = clampf(TEMP_OFFSET_C, OFS_MIN, OFS_MAX);
}

static void saveSettings(){
  prefs.begin("hotplate", false);
  prefs.putFloat("band", APPROACH_BAND_C);
  prefs.putUInt("win", WINDOW_MS);
  prefs.putFloat("pwr", MAX_DUTY);
  prefs.putFloat("ofs", TEMP_OFFSET_C);
  prefs.end();
}

// shared heater function (Manual + Reflow)
static bool computeRelayBurst(bool requestHeat, bool sensorOK, float tempC, float activeSet, uint32_t nowMs){
  if(!requestHeat || !sensorOK) return false;

  float err = activeSet - tempC; // + = needs heat
  if(err <= 0.0f) return false;  // at/above target -> OFF

  float duty = err / APPROACH_BAND_C;
  duty = clampf(duty, 0.0f, MAX_DUTY);

  if(WINDOW_MS == 0) return false;
  uint32_t phase = nowMs % WINDOW_MS;
  return phase < (uint32_t)(duty * (float)WINDOW_MS);
}

// Safer thermistor read
static bool readThermistor(float &outC){
  int raw = analogRead(PIN_NTC);
  if(raw <= 0 || raw >= 4095) return false;

  float v = (raw / 4095.0f) * VREF;
  v = clampf(v, 0.001f, VREF - 0.001f);

  float rNTC = R_FIXED * (v / (VREF - v));
  float invT = (1.0f / NTC_T0K) + (1.0f / NTC_BETA) * logf(rNTC / NTC_R0);
  float tK = 1.0f / invT;

  outC = tK - 273.15f;
  if(outC < -50.0f || outC > 450.0f){
    outC = 0.0f;
    return false;
  }
  return true;
}

// ROT=3 mapping with 3-sample median filter for better touch stability
static bool getTouchXY(int &x, int &y){
  // Fast exit when IRQ says no touch; still falls back to touched() if needed
  if(!touchscreen.tirqTouched() && !touchscreen.touched()) return false;
  if(!touchscreen.touched()) return false;

  TS_Point p1 = touchscreen.getPoint();

  delay(4);
  if(!touchscreen.touched()) return false;
  TS_Point p2 = touchscreen.getPoint();

  delay(4);
  if(!touchscreen.touched()) return false;
  TS_Point p3 = touchscreen.getPoint();

  int rawX = median3(p1.y, p2.y, p3.y);
  int rawY = median3(p1.x, p2.x, p3.x);

  x = map(rawX, YMIN, YMAX, W - 1, 0);
  y = map(rawY, XMIN, XMAX, 0, H - 1);

  x = (int)clampf((float)x, 0, W - 1);
  y = (int)clampf((float)y, 0, H - 1);
  return true;
}

// ========= REFLOW CURVE =========
static float reflowSetpoint(float tsec){
  float preheatC = peakC * 0.625f;
  float soakC    = peakC * 0.75f;

  preheatC = clampf(preheatC, 110.0f, peakC - 70.0f);
  soakC    = clampf(soakC, preheatC + 10.0f, peakC - 20.0f);

  if(tsec < 90.0f)  return 25.0f + (preheatC - 25.0f) * (tsec / 90.0f);
  if(tsec < 180.0f) return preheatC + (soakC - preheatC) * ((tsec - 90.0f) / 90.0f);
  if(tsec < 240.0f) return soakC + (peakC - soakC) * ((tsec - 180.0f) / 60.0f);
  if(tsec < 270.0f) return peakC;
  if(tsec < 420.0f) return peakC + (50.0f - peakC) * ((tsec - 270.0f) / 150.0f);
  return 25.0f;
}

static const char* reflowStage(float tsec){
  if(tsec < 90)  return "Preheat";
  if(tsec < 180) return "Soak";
  if(tsec < 240) return "Ramp";
  if(tsec < 270) return "Peak";
  if(tsec < 420) return "Cool";
  return "Done";
}

// ========= DRAWING =========
static void layoutButtons(){
  int marginX = 10;
  int x = marginX;
  int wFull = SIDE_W - 2*marginX;
  int gapX = 8;
  int gapY = 12;

  int yTop = PLOT_Y;
  int availH = (H - 6) - PLOT_Y;

  int rowH = (int)clampf((float)(availH / 3), 40.0f, 60.0f);
  int yRow = yTop + (availH - rowH);

  int heatH = yRow - yTop - gapY;
  if(heatH < 40) heatH = 40;

  btnHeatR = { x, yTop, wFull, heatH };

  int wEach = (wFull - gapX) / 2;
  btnMinusR = { x, yRow, wEach, rowH };
  btnPlusR  = { x + wEach + gapX, yRow, wEach, rowH };
}

static void drawGearIcon(int cx, int cy, int r, uint16_t col){
  tft.drawCircle(cx, cy, r, col);
  tft.drawCircle(cx, cy, r - 3, col);
  for(int i=0;i<8;i++){
    float a = i * (3.14159265f / 4.0f);
    int x0 = cx + (int)((r - 1) * cosf(a));
    int y0 = cy + (int)((r - 1) * sinf(a));
    int x1 = cx + (int)((r + 2) * cosf(a));
    int y1 = cy + (int)((r + 2) * sinf(a));
    tft.drawLine(x0, y0, x1, y1, col);
  }
}

static void drawTabs(){
  uint16_t mFill = (mode == MODE_MANUAL)   ? TFT_DARKGREY : TFT_BLACK;
  uint16_t rFill = (mode == MODE_REFLOW)   ? TFT_DARKGREY : TFT_BLACK;
  uint16_t sFill = (mode == MODE_SETTINGS) ? TFT_DARKGREY : TFT_BLACK;

  tft.fillRect(tabManualR.x, tabManualR.y, tabManualR.w, tabManualR.h, mFill);
  tft.fillRect(tabReflowR.x, tabReflowR.y, tabReflowR.w, tabReflowR.h, rFill);
  tft.fillRect(tabSetR.x,    tabSetR.y,    tabSetR.w,    tabSetR.h,    sFill);

  tft.drawFastHLine(0, TAB_H-1, W, TFT_WHITE);
  tft.drawFastVLine(tabReflowR.x, 0, TAB_H, TFT_WHITE);
  tft.drawFastVLine(tabSetR.x,    0, TAB_H, TFT_WHITE);

  tft.setTextDatum(MC_DATUM);
  tft.setTextSize(2);

  tft.setTextColor(TFT_WHITE, mFill);
  tft.drawString("MANUAL", tabManualR.x + tabManualR.w/2, TAB_H/2);

  tft.setTextColor(TFT_WHITE, rFill);
  tft.drawString("REFLOW", tabReflowR.x + tabReflowR.w/2, TAB_H/2);

  int gx = tabSetR.x + tabSetR.w/2;
  int gy = TAB_H/2;
  drawGearIcon(gx, gy, 7, TFT_WHITE);
}

static void drawButton(const Rect& r, const char* text, uint16_t fill, uint16_t border){
  tft.fillRoundRect(r.x, r.y, r.w, r.h, 10, fill);
  tft.drawRoundRect(r.x, r.y, r.w, r.h, 10, border);
  tft.setTextDatum(MC_DATUM);
  tft.setTextSize(2);
  tft.setTextColor(TFT_BLACK, fill);
  tft.drawString(text, r.x + r.w/2, r.y + r.h/2);
}

static void drawBottomBar(){
  tft.fillRect(0, PLOT_Y, SIDE_W, H - PLOT_Y, TFT_BLACK);
  tft.drawFastVLine(SIDE_W, PLOT_Y, H - PLOT_Y, TFT_DARKGREY);

  if(mode == MODE_MANUAL){
    drawButton(btnHeatR,  "HEAT", heatOn ? TFT_GREEN : TFT_DARKGREY, TFT_WHITE);
    drawButton(btnMinusR, "-",    TFT_DARKGREY, TFT_WHITE);
    drawButton(btnPlusR,  "+",    TFT_DARKGREY, TFT_WHITE);
  } else if(mode == MODE_REFLOW) {
    drawButton(btnHeatR,  "HEAT", reflowRunning ? TFT_RED : TFT_DARKGREY, TFT_WHITE);
    drawButton(btnMinusR, "-",    TFT_DARKGREY, TFT_WHITE);
    drawButton(btnPlusR,  "+",    TFT_DARKGREY, TFT_WHITE);
  } else {
    drawButton(btnHeatR,  "SAVE", TFT_BLUE, TFT_WHITE);
    drawButton(btnMinusR, "-",    TFT_DARKGREY, TFT_WHITE);
    drawButton(btnPlusR,  "+",    TFT_DARKGREY, TFT_WHITE);
  }
}

static void drawRelayDot(bool on){
  int cx = RELAY_DOT_X;
  int cy = RELAY_DOT_Y;
  int r  = RELAY_DOT_R;

  tft.fillRect(cx - r - 2, cy - r - 2, (r + 2) * 2, (r + 2) * 2, TFT_BLACK);
  tft.fillCircle(cx, cy, r, on ? TFT_GREEN : TFT_RED);
  tft.drawCircle(cx, cy, r, TFT_WHITE);
}

static void drawValues(){
  tft.fillRect(10, 30, W - 44, 40, TFT_BLACK);

  tft.setTextSize(2);
  tft.setTextDatum(TL_DATUM);

  tft.setTextColor(TFT_YELLOW, TFT_BLACK);
  tft.drawString(String("TEMP: ") + String(tempC, 1) + " C", 10, 30);

  tft.setTextColor(TFT_GREEN, TFT_BLACK);
  tft.drawString(String("SET : ") + String(activeSetForDisplay, 0) + " C", 10, 50);

  bool heatEnabledShown = (mode == MODE_MANUAL) ? heatOn : reflowRunning;

  tft.setTextDatum(TR_DATUM);
  int rightX = W - 34;

  tft.setTextColor(heatEnabledShown ? TFT_GREEN : TFT_RED, TFT_BLACK);
  tft.drawString(heatEnabledShown ? "HEAT : ON " : "HEAT : OFF", rightX, 30);

  tft.setTextColor(sensorOK ? TFT_CYAN : TFT_ORANGE, TFT_BLACK);
  tft.drawString(sensorOK ? "SENSOR: OK" : "SENSOR: BAD", rightX, 50);
}

// ---- Plot mapping (reflow) ----
static int mapTimeToX(float tsec){
  float x = (tsec / REFLOW_TOTAL_S) * (float)(PLOT_W - 1);
  return PLOT_X + (int)clampf(x, 0, (float)(PLOT_W - 1));
}

static int plotYmax(){
  return (int)clampf(peakC + 10.0f, 200.0f, 450.0f);
}

static int mapTempToY(float tc){
  float tMin = 25.0f;
  float tMax = (float)plotYmax();
  float norm = (tc - tMin) / (tMax - tMin);
  norm = clampf(norm, 0.0f, 1.0f);
  return PLOT_Y + (PLOT_H - 1) - (int)(norm * (float)(PLOT_H - 1));
}

static void drawPlotFrame(){
  tft.fillRect(PLOT_X, PLOT_Y, PLOT_W, PLOT_H, TFT_BLACK);
  tft.drawRect(PLOT_X, PLOT_Y, PLOT_W, PLOT_H, TFT_DARKGREY);
}

static void drawPlotInfo(float tsec){
  tft.fillRect(10, INFO_Y, W-20, 12, TFT_BLACK);
  tft.setTextSize(1);
  tft.setTextDatum(TL_DATUM);
  tft.setTextColor(TFT_WHITE, TFT_BLACK);
  if(reflowRunning){
    tft.drawString(String(reflowStage(tsec)) + " t=" + String((int)tsec) + "s", 10, INFO_Y);
  } else {
    tft.drawString(String("Peak=") + String((int)peakC) + "C", 10, INFO_Y);
  }
}

static void drawReflowBlueCurveOnce(){
  drawPlotFrame();
  int lastX = mapTimeToX(0);
  int lastY = mapTempToY(reflowSetpoint(0));
  for(float tt = PLOT_STEP_S; tt <= REFLOW_TOTAL_S; tt += PLOT_STEP_S){
    int x = mapTimeToX(tt);
    int y = mapTempToY(reflowSetpoint(tt));
    tft.drawLine(lastX, lastY, x, y, TFT_BLUE);
    lastX = x;
    lastY = y;
  }
  lastProgIdx = 0;
  lastDotX = lastDotY = -1;
  lastDotIdx = -1;
  drawPlotInfo(0.0f);
}

static void redrawSegmentForIdx(int idx){
  int points = (int)(REFLOW_TOTAL_S / PLOT_STEP_S) + 1;
  if(idx < 0 || idx >= points-1) return;
  float t0 = idx * PLOT_STEP_S;
  float t1 = (idx + 1) * PLOT_STEP_S;
  int x0 = mapTimeToX(t0);
  int y0 = mapTempToY(reflowSetpoint(t0));
  int x1 = mapTimeToX(t1);
  int y1 = mapTempToY(reflowSetpoint(t1));
  tft.drawLine(x0, y0, x1, y1, TFT_BLUE);
  if(idx < lastProgIdx) tft.drawLine(x0, y0, x1, y1, TFT_RED);
}

static void updateDot(int idxNow){
  if(lastDotX >= 0 && lastDotY >= 0){
    tft.fillCircle(lastDotX, lastDotY, 4, TFT_BLACK);
    redrawSegmentForIdx(lastDotIdx - 1);
    redrawSegmentForIdx(lastDotIdx);
    redrawSegmentForIdx(lastDotIdx + 1);
  }
  float t = idxNow * PLOT_STEP_S;
  int cx = mapTimeToX(t);
  int cy = mapTempToY(reflowSetpoint(t));
  tft.fillCircle(cx, cy, 3, TFT_WHITE);
  lastDotX = cx;
  lastDotY = cy;
  lastDotIdx = idxNow;
}
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
void loop(){
  // ---- Touch: click on release, but more forgiving ----
  static bool touchDown = false;
  static uint32_t downMs = 0;
  static int xStart = 0, yStart = 0;
  static int xLast  = 0, yLast  = 0;
  static int maxDx = 0, maxDy = 0;
  static uint32_t lastClickMs = 0;

  int tx, ty;
  bool pressed = getTouchXY(tx, ty);

  if(pressed){
    if(!touchDown){
      touchDown = true;
      downMs = millis();
      xStart = xLast = tx;
      yStart = yLast = ty;
      maxDx = maxDy = 0;
    } else {
      xLast = tx;
      yLast = ty;
      int dx = abs(xLast - xStart);
      int dy = abs(yLast - yStart);
      if(dx > maxDx) maxDx = dx;
      if(dy > maxDy) maxDy = dy;
    }
  } else {
    if(touchDown){
      uint32_t upMs = millis();
      uint32_t held = upMs - downMs;

      if(held >= 15 && maxDx <= 45 && maxDy <= 45){
        if(upMs - lastClickMs >= 80){
          lastClickMs = upMs;
          int cx = (xStart + xLast) / 2;
          int cy = (yStart + yLast) / 2;
          handleClick(cx, cy);
        }
      }
    }
    touchDown = false;
  }

  // ---- Control update (every 200ms) ----
  static uint32_t lastCtrlMs = 0;
  uint32_t now = millis();
  if(now - lastCtrlMs < 200) return;
  lastCtrlMs = now;

  // ---- Sensor read with debounce ----
  float t;
  bool valid = readThermistor(t);

  if(valid){
    sensorBadCnt = 0;
    if(sensorGoodCnt < 255) sensorGoodCnt++;
    if(sensorGoodCnt >= SENSOR_GOOD_RECOVER) sensorOK = true;

    // Filter raw sensor first, then apply offset
    if(sensorOK) tempSensorC = 0.8f * tempSensorC + 0.2f * t;
    else         tempSensorC = t;

    tempC = tempSensorC + TEMP_OFFSET_C;
  } else {
    sensorGoodCnt = 0;
    if(sensorBadCnt < 255) sensorBadCnt++;
    if(sensorBadCnt >= SENSOR_BAD_TRIP) sensorOK = false;
    // keep last tempC
  }

  bool requestHeat = false;
  float activeSet = setC;

  // ========= REFLOW TIMING: PAUSE IF BEHIND =========
  if(mode == MODE_REFLOW && reflowRunning){

    if(reflowLastTickMs == 0) reflowLastTickMs = now;
    float dt = (now - reflowLastTickMs) / 1000.0f;
    reflowLastTickMs = now;
    if(dt < 0) dt = 0;
    if(dt > 1.0f) dt = 1.0f;

    float spNow = reflowSetpoint(reflowProgS);

    if(sensorOK){
      if(reflowProgS < 270.0f){
        if(tempC >= (spNow - REFLOW_SYNC_BAND_C)){
          reflowProgS += dt;
        }
      } else {
        reflowProgS += dt;
      }
    }

    float tsec = reflowProgS;

    if(tsec >= REFLOW_TOTAL_S){
      reflowRunning = false;
      reflowLastTickMs = 0;
      requestHeat = false;
      activeSet = peakC;
      drawPlotInfo(0.0f);
    } else {
      requestHeat = true;
      activeSet = reflowSetpoint(tsec);
    }

  } else {
    // ========= MANUAL: ramp + hold =========
    if(mode == MODE_MANUAL){
      requestHeat = heatOn;

      if(heatOn){
        if(manualRampLastMs == 0) manualRampLastMs = now;
        float dt = (now - manualRampLastMs) / 1000.0f;
        manualRampLastMs = now;
        if(dt < 0) dt = 0;
        if(dt > 1.0f) dt = 1.0f;

        if(setC < manualRampSetC){
          manualRampSetC = setC;
        } else if(setC > manualRampSetC) {
          if(sensorOK){
            if(tempC >= (manualRampSetC - MANUAL_SYNC_BAND_C)){
              manualRampSetC += MANUAL_RAMP_CPS * dt;
              if(manualRampSetC > setC) manualRampSetC = setC;
            }
          }
        }

        activeSet = manualRampSetC;
      } else {
        manualRampLastMs = 0;
        activeSet = setC;
      }

    } else {
      requestHeat = false;
      if(mode == MODE_REFLOW) activeSet = peakC;
      else                    activeSet = setC;
    }
  }

  // ---- Relay logic ----
  relayOn = computeRelayBurst(requestHeat, sensorOK, tempC, activeSet, now);
  ssrWrite(relayOn);

  if(mode == MODE_MANUAL) activeSetForDisplay = setC;
  else                    activeSetForDisplay = activeSet;

  // ---- Minimal redraw ----
  drawValues();

  if(relayOn != lastRelayOnDrawn){
    drawRelayDot(relayOn);
    lastRelayOnDrawn = relayOn;
  }

  if(mode != lastModeDrawn || heatOn != lastHeatOnDrawn || reflowRunning != lastReflowRunDrawn){
    drawTabs();
    drawBottomBar();
    lastModeDrawn      = mode;
    lastHeatOnDrawn    = heatOn;
    lastReflowRunDrawn = reflowRunning;

    if(mode == MODE_SETTINGS){
      drawSettingsPanel();
    }
  }

  // Manual plot update (1 Hz)
  if(mode == MODE_MANUAL){
    static uint32_t lastManPlotMs = 0;
    if(now - lastManPlotMs >= 1000){
      lastManPlotMs = now;
      if(!manualHistInit) manualPlotInitNow();
      manualPlotPush(tempC);
      drawManualPlot();
    }
  }

  // Reflow plot incremental
  if(mode == MODE_REFLOW){
    static uint32_t lastPlotMs = 0;
    if(now - lastPlotMs >= 400){
      lastPlotMs = now;
      if(reflowRunning){
        float tsec = reflowProgS;
        drawReflowProgressIncrement(tsec);
      } else {
        drawPlotInfo(0.0f);
      }
    }
  }
}
